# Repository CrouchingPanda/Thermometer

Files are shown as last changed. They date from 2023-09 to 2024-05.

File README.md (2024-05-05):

# Thermometer

Board for temperature measurement built around MLX90614 infrared surface temperature sensor.

## Platform

Arduino core used is Raspberry Pi Pico / RP2040 by Earle F. Philhower, III v3.7.0.

[InterboardSerial](https://github.com/CrouchingPanda/InterboardSerial) custom library is used 
for communicating with the calibration board.

## Libraries

| Title | Version |
|---|---|
| lvgl | 8.3.11  |
| TFT_eSPI | 2.5.34  |
| Smoothed | 1.2.0 |
| SerialTransfer | 3.1.3 |
| NeoPixelConnect | 1.2.0 |
| JLed | 4.13.1  |
| Adafruit MLX90614  | 2.1.5 |
| Adafruit LC709203F | 1.3.4 |
| Adafruit FT6206 | 1.1.0 |
| Adafruit BusIO | 1.15.0  |
| ArduinoJson | 7.0.3 |
| InterboardSerial | latest  |

## Theory Highlights

### For any object

```math
ε + R + 𝜏 = 1
```

$ε$ = Emissivity

$R$ = Reflectivity

$𝜏$ = Transmissivity

### For non-transparent object

```math
𝜏 = 0; ε + R = 1
```

### Stefan-Boltzmann Law

```math
M_e = P/A = εσ(T_o^4 - T_a^4)
```

$M_e$ = radiant exitance = defined as $P/A$

$P$ = energy per unit time = power = radiant flux

$A$ = area

$σ$ = Stefan's constant

$T_o$ = temperature of an object

$T_a$ = ambient temperature

### Sensor/object arrangement

```
 sensor (M_s)                                object
+-----------        emitted (M_o)           +------+
|            <==============================|      |
|            <-----------------------------_|      |
+-----------        reflected (M_r)        /|------+
                                          /
                                         /
                                        / ambient 
                                       / to be reflected									   
```

```math
M_s = M_o + M_r = εσ(T_o^4 - T_s^4) + Rσ(T_r^4 - T_s^4)
```

$M_s$ = total sensor exitance

$M_o$ = exitance coming from the object itself

$M_r$ = exitance coming from the surroundings = radiation reflected by the object

$T_o$ = object's temperature

$T_s$ = sensor's temperature (on its die)

$T_r$ = room (ambient, background) temperature

### Application

MLX90614 leverages the above to come up with its temperature readings. It has an element monitoring its own 
temperature, as well as another sensor registering incident energy flux. It uses an emissivity value of `1.00` 
by default. As a note, in the equation above the sensor's firmware assumes $T_s = T_r$.

A way to adjust the calculations for a different emissivity is to get the temperature reading from the device with
its default emissivity, thereby getting the incident flux value. Then use the above formula backward, using an arbitrary
emissivity of choice and now taking the temperature for the unknown variable.

Also, when doing calculations manually on MCU, the $T_s = T_r$ assumption can be tweaked, as it has been noted that 
in real-life scenarios the sensor can have higher temperature (perhaps due to self-heating) than the background.

### Calculations

First, we get both the object temperature $T_o$ as well as the sensor temperature $T_s$ with device's emissivity $ε$
set to `1.0`. For the sake of this example, we get $T_o = 73.0$ and $T_s = 69.0$. For the sake of simplicity the room 
temperature is assumed the same as the sensor temperature. Applying the equation above we get:

```math
M_s = 1 * σ * ((73.0)^4 - (69.0)^4) + (1 - 1) * σ * ((69.0)^4 - (69.0)^4)
```

```math
M_s / σ  = 5,731,120
```

Now we calculate the actual object temperature using what we believe is the real emissivity of whatever material 
we are measuring. Let's say the material is anodized aluminum with emissivity `0.77`. Applying the same formula
backward we get:

```math
M_s = 0.77 * σ * (T_o^4 - (69.0)^4) + 0.23 * σ * ((69.0)^4 - (69.0)^4)
```

```math
M_s / σ = 0.77 * T_o^4 - 17,453,683.17
```

```math
5,731,120 = 0.77 * T_o^4 - 17,453,683.17
```

```math
T_o^4 = 30,110,133.98
```

```math
T_o = 74.07
```

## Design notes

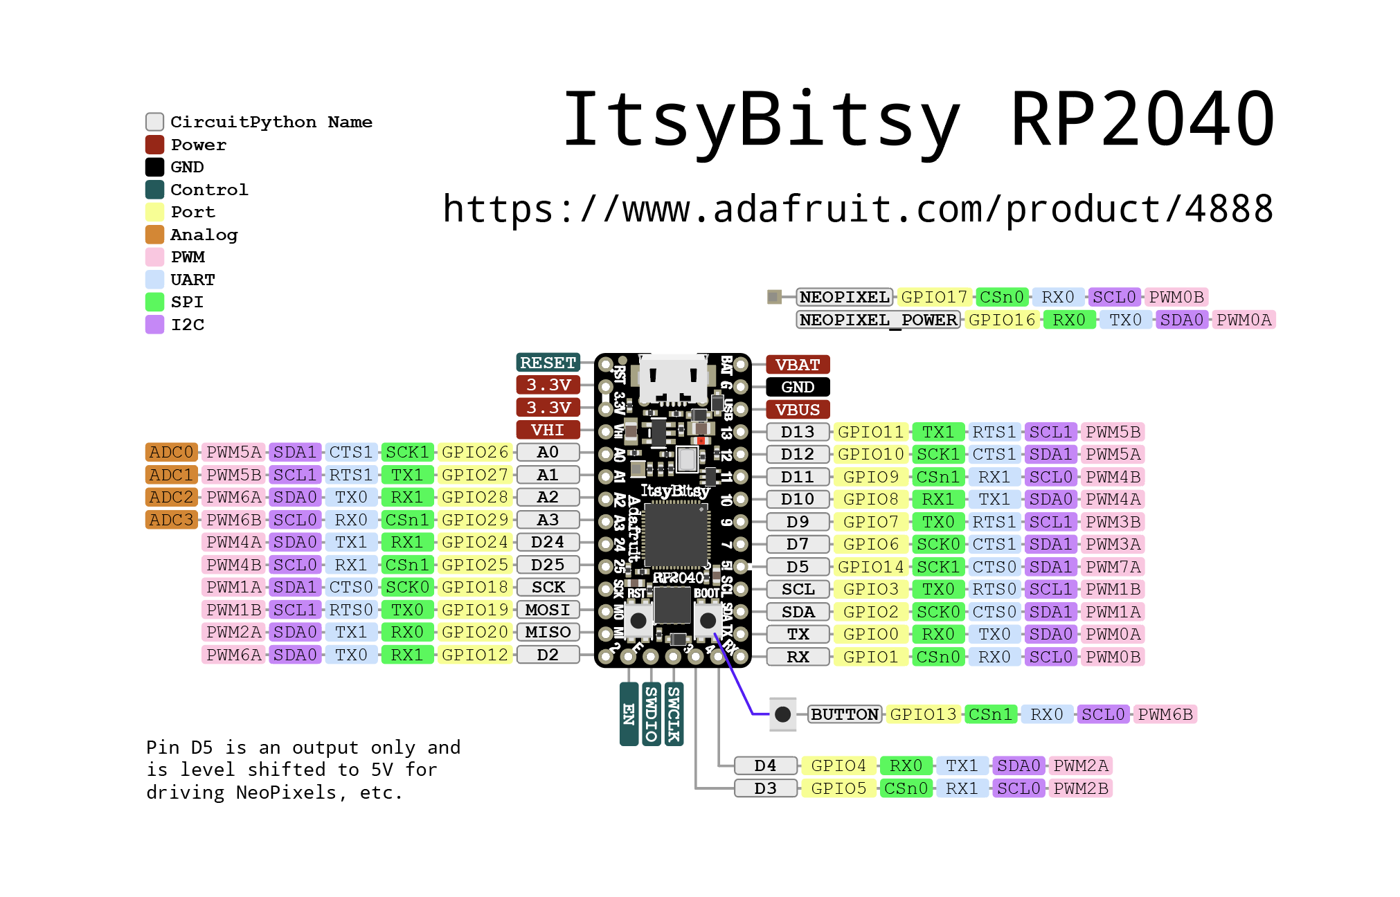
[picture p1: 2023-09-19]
resources/parts/ItsyBitsy RP2040 pinout.png

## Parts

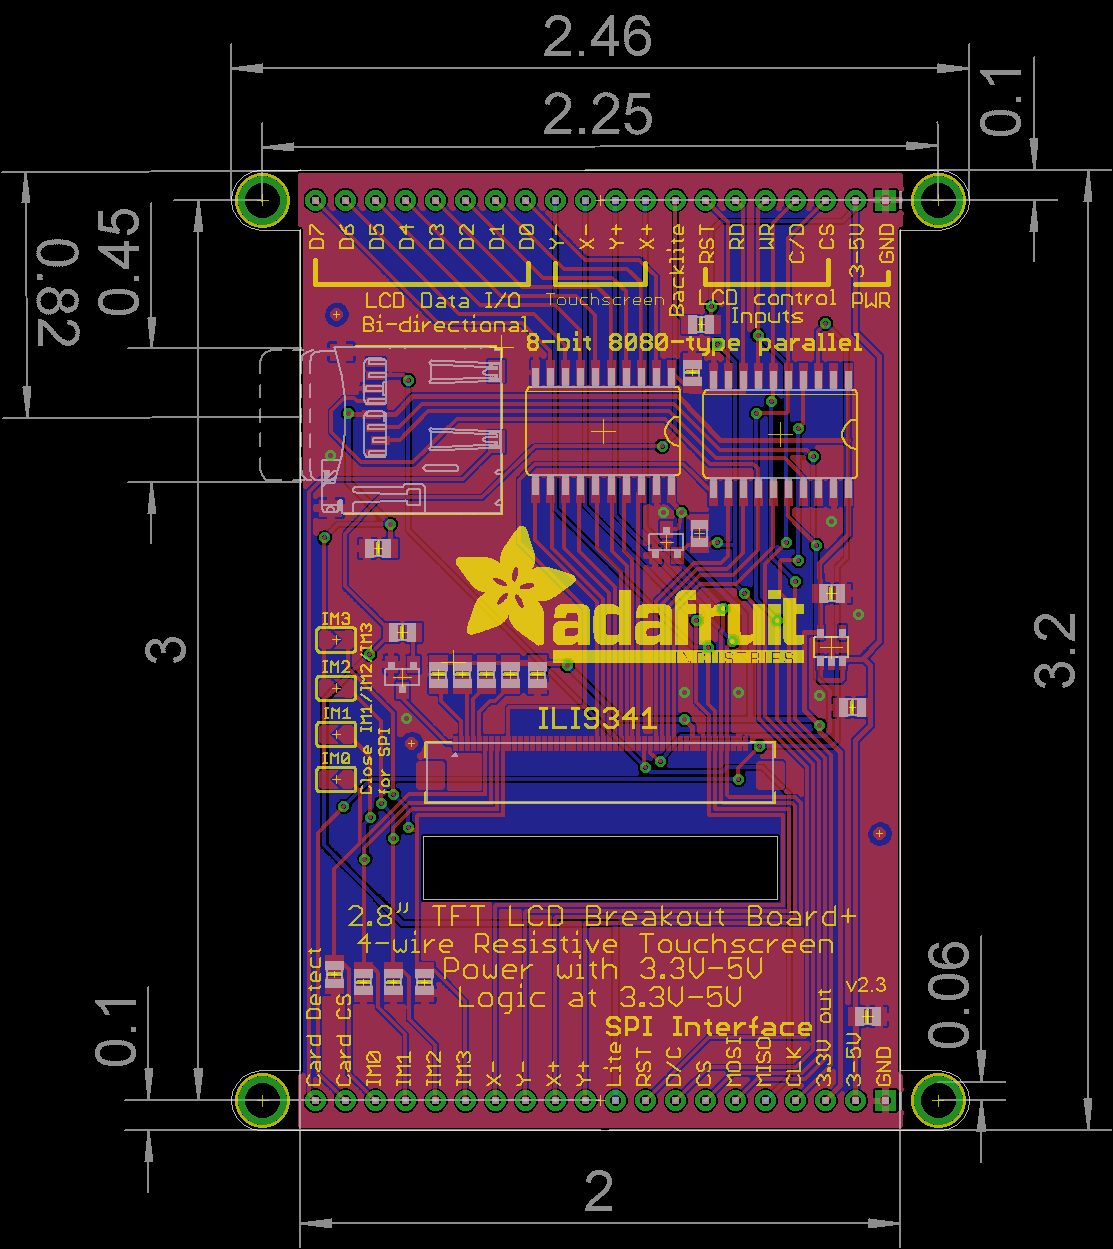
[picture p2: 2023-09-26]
resources/parts/adafruit_products_cap_touch.png

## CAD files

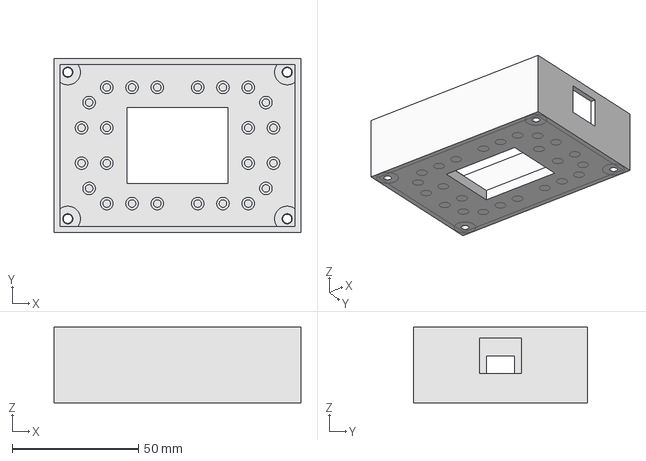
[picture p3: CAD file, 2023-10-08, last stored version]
resources/models/thermistor board case.FCStd
97.8 x 68.8 x 30.0 mm

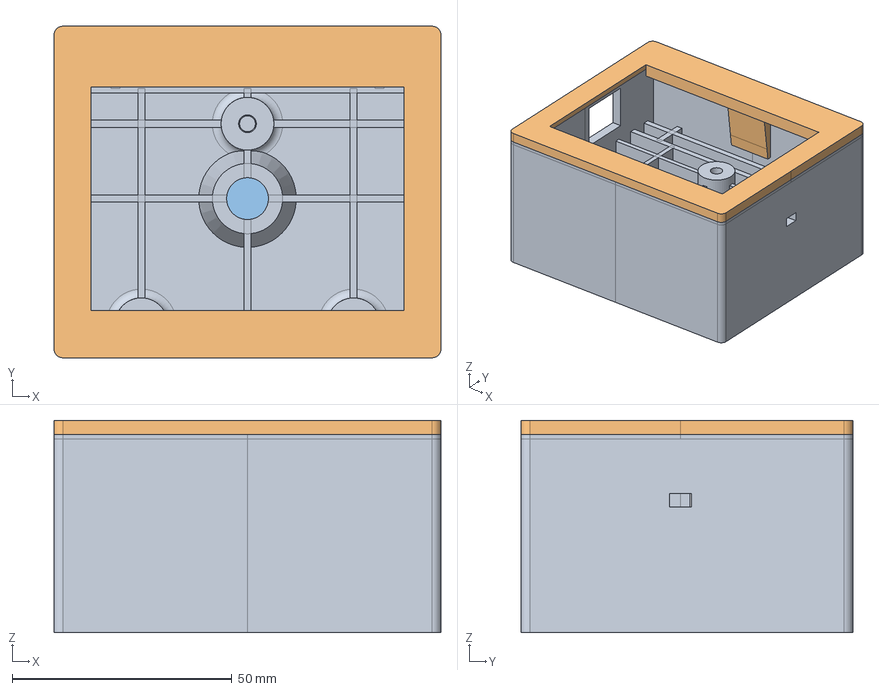
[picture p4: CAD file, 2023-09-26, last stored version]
resources/models/ir board case.FCStd
88.0 x 75.4 x 48.3 mm
Case
Lid
SensorPlug

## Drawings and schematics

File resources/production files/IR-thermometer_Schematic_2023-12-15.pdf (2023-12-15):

RX 20 TX 21 SDA 22 SCL 23 D5 24 D7 25 D9 26 D10 27 D11 28 D12 29 D13 30 VBUS 31 GND 32 VBAT 33

## ItsyBitsy

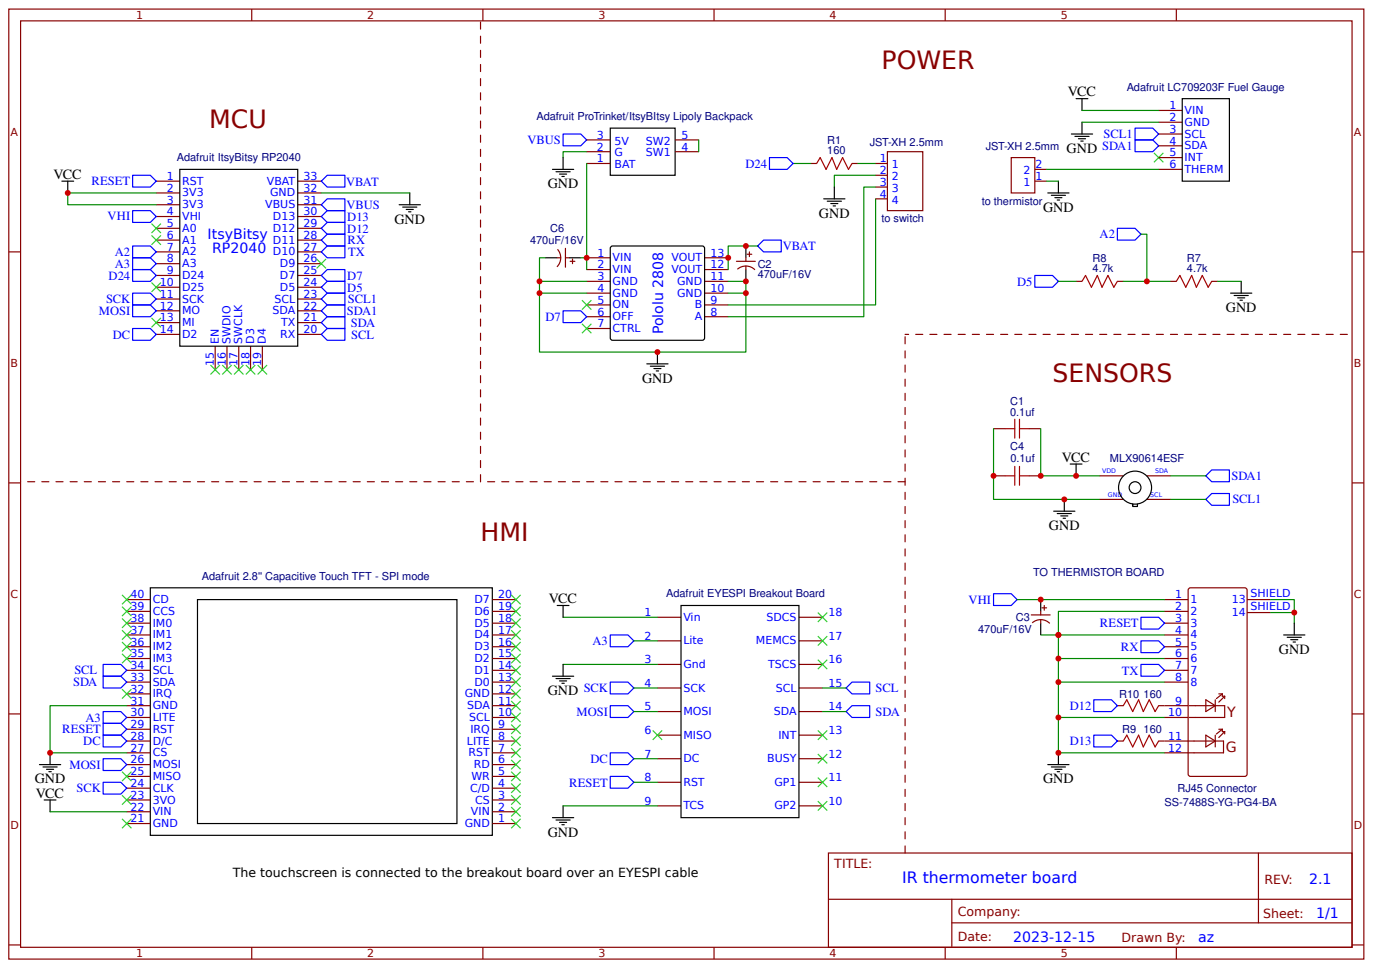
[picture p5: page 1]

Adafruit ProTrinket/ItsyBItsy Lipoly Backpack

Adafruit 2.8'' Capacitive Touch TFT - SPI mode

The touchscreen is connected to the breakout board over an EYESPI cable

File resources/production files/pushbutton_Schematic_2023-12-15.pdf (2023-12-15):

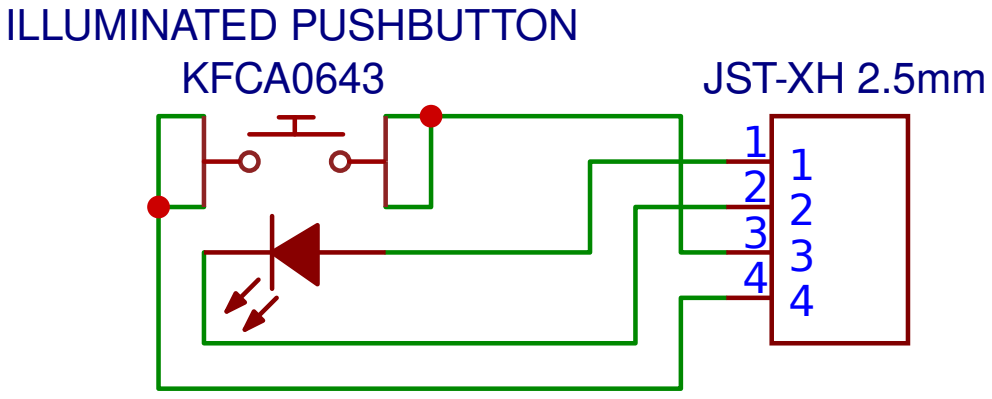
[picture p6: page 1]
JST-XH 2.5mm 1 1 2 2 3 3 4 4; ILLUMINATED PUSHBUTTON; TITLE:; Pushbutton breakout; REV: 1.0; Date:; Sheet: 1/1; Company:; KFCA0643

Drawn By: az

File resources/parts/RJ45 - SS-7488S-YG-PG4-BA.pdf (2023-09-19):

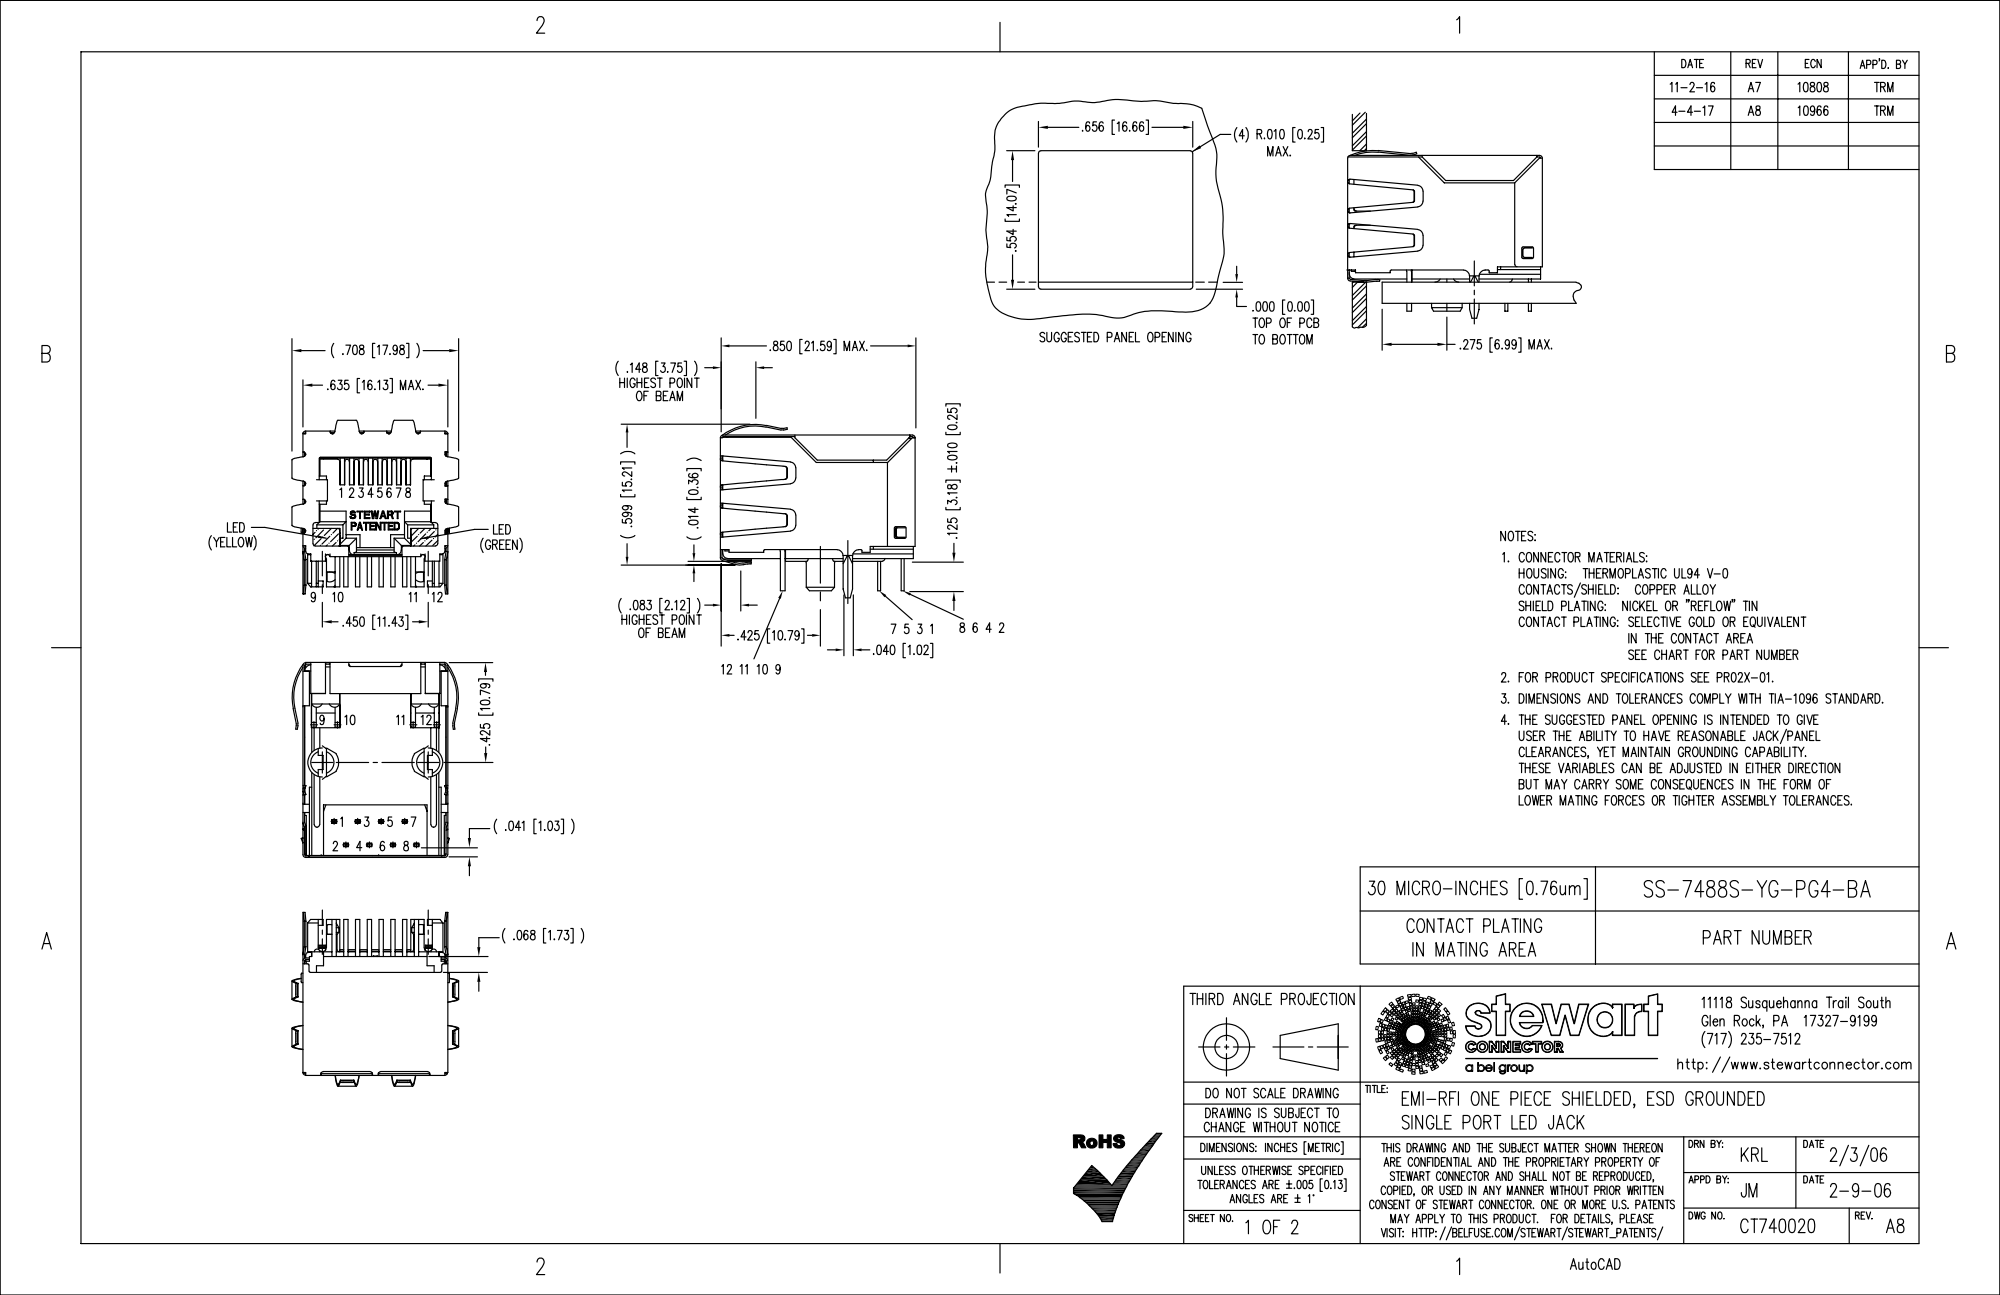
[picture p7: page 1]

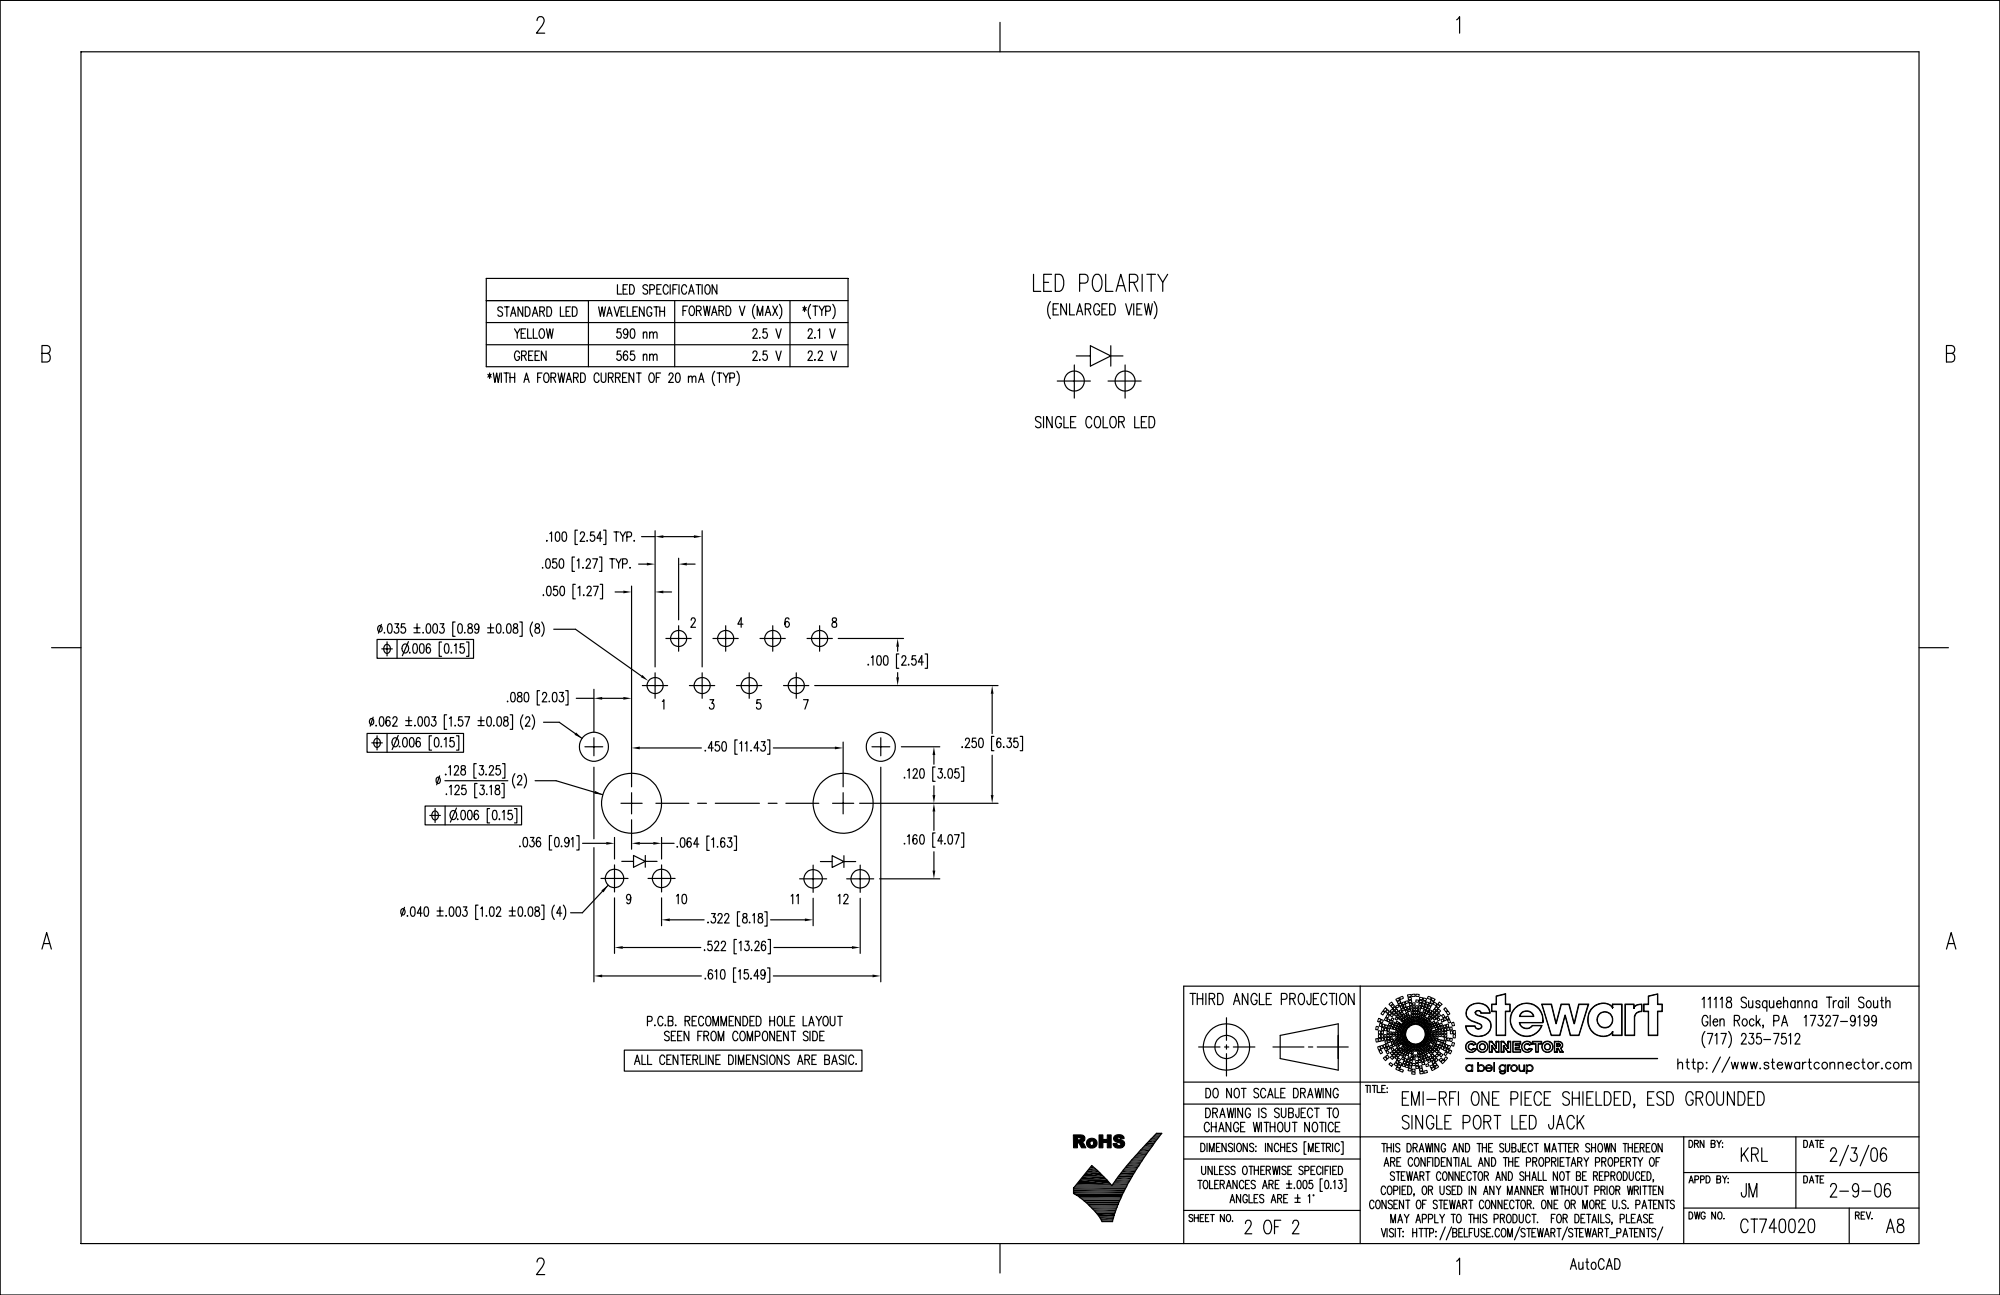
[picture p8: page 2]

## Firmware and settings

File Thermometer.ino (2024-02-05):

#include <Wire.h>

#include "src/hmi/HMI.h"
#include "src/calibration/CalibrationBoardReceiver.h"
#include "src/hardware/MelexisThermometer.h"
#include "src/hardware/Battery.h"
#include "src/hardware/PowerButtonLED.h"
#include "src/monitor/HealthMonitor.h"
#include "src/monitor/ActivityMonitor.h"

// faster doesn't work, not exactly sure why
constexpr uint32_t I2C_FREQUENCY = 70'000;

void setup() {
  HMI.begin();
  HMI.showLoadingScreen();
  HMI.setLoadingPercent(10);

  HealthMonitor.begin();
  HMI.setLoadingPercent(20);

  PowerLED.begin();
  HMI.setLoadingPercent(30);

  ActivityMonitor.begin();
  HMI.setLoadingPercent(40);

  Wire1.setClock(I2C_FREQUENCY);
  HMI.setLoadingPercent(50);

  Thermometer.begin();
  HMI.setLoadingPercent(60);

  LiPoBattery.begin();
  HMI.setLoadingPercent(70);

  CalibrationReceiver.begin();
  HMI.setLoadingPercent(80);

  HMI.startLvgl();
  HMI.setLoadingPercent(90);

  HMI.setObjectTemperatureWriter(
    [](){ return Thermometer.objectTemperatureFahrenheit(); }
  );

  HMI.setRoomTemperatureWriter(
    [](){ return Thermometer.roomTemperatureFahrenheit(); }
  );

  HMI.setOnDieTemperatureWriter(
    [](){ return Thermometer.onDieTemperatureFahrenheit(); }
  );

  HMI.setEmissivityWriter(
    [](){ return Thermometer.getEmissivity(); }
  );

  HMI.setEmissivityReader(
    [](float emissivity){ Thermometer.setEmissivity(emissivity); }
  );

  HMI.setBatteryPercentageWriter(
    [](){ return LiPoBattery.chargePercentage(); }
  );

  HMI.setBatteryChargingStatusWriter(
    [](){ return LiPoBattery.isCharging(); }
  );

  HMI.setBatteryTemperatureWriter(
    [](){ return LiPoBattery.temperatureFahrenheit(); }
  );

  HMI.setCalibrationBoardConnectionStatusWriter(
    [](){ return CalibrationReceiver.isConnected(); }
  );

  HMI.setPrimaryThermistorTemperatureWriter(
    [](){ return CalibrationReceiver.primaryThermistorTemperatureFahrenheit(); }
  );

  HMI.setSecondaryThermistorTemperatureWriter(
    [](){ return CalibrationReceiver.secondaryThermistorTemperatureFahrenheit(); }
  );

  HMI.onActivity(
    [](){ ActivityMonitor.registerActivity(); }
  );

  HMI.setLowPowerModeTimeoutWriter(
    [](){ return ActivityMonitor.getLowPowerTimeoutMins(); }
  );

  HMI.setPowerOffTimeoutWriter(
    [](){ return ActivityMonitor.getPowerOffTimeoutMins(); }
  );

  HMI.setLowPowerModeTimeoutReader(
    [](uint8_t minutes){ ActivityMonitor.setLowPowerTimeoutMins(minutes); }
  );

  HMI.setPowerOffTimeoutReader(
    [](uint8_t minutes){ ActivityMonitor.setPowerOffTimeoutMins(minutes); }
  );

  HMI.setPowerIndicatorOnBrightnessWriter(
    [](){ return PowerLED.getOnBrightness(); }
  );

  HMI.setPowerIndicatorMaxBreathBrightnessWriter(
    [](){ return PowerLED.getMaxBreathBrightness(); }
  );

  HMI.setPowerIndicatorOnBrightnessReader(
    [](uint8_t brightness){ PowerLED.setOnBrightness(brightness); }
  );

  HMI.setPowerIndicatorMaxBreathBrightnessReader(
    [](uint8_t brightness){ PowerLED.setMaxBreathBrightness(brightness); }
  );

  HMI.setObjectTemperatureSmoothingFactorWriter(
    []() { return Thermometer.getObjectTemperatureSmoothingFactor(); }
  );

  HMI.setObjectTemperatureSmoothingFactorReader(
    [](uint8_t factor) { Thermometer.setObjectTemperatureSmoothingFactor(factor); }
  );

  HMI.setRoomTemperatureOffsetWriter(
    []() { return Thermometer.getRoomTemperatureOffsetCelsius(); }
  );

  HMI.setRoomTemperatureOffsetReader(
    [](float offset) { Thermometer.setRoomTemperatureOffsetCelsius(offset); }
  );

  ActivityMonitor.onLowPowerMode(
    [](){ HMI.initLowPowerMode(); }
  );

  ActivityMonitor.onDefaultMode(
    [](){ HMI.initDefaultMode(); }
  );

  HMI.setLoadingPercent(100);
  HMI.switchFromLoadingScreen();
}

void loop() {
  LiPoBattery.isCharging() ? PowerLED.breathe() : PowerLED.on();
  HealthMonitor.run();
  CalibrationReceiver.run();
  ActivityMonitor.run();
  HMI.run();
}

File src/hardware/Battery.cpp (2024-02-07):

#include "Battery.h"

#include <stdint.h>

#include <Arduino.h>

#include <Wire.h>

#include <Adafruit_LC709203F.h>

constexpr uint16_t ADC_BITS = 12;

// we always read 1/2 of battery voltage because full (4.2V) is too much
// for the analog pin
constexpr float VOLTAGE_DIVIDER_RATIO = 2.0;
constexpr float MIN_CHARGING_VOLTAGE_MV = 4.5;
constexpr float REF_BOARD_VOLTAGE = 3.3;

constexpr uint8_t CHARGING_STATUS_CHECK_PIN = A2;
constexpr uint8_t VOLTAGE_PIN = 14;

// per LC709203F datasheet for 500mAh 3.7V battery
constexpr uint8_t BATTERY_APA = 0x10;
constexpr uint8_t BATTERY_PROFILE = 1;

// B25/B50 for thermistor P/N NXFT15XH103FEAB050
constexpr uint16_t BATTERY_THERMISTOR_B_VALUE = 3380;

void Battery::begin() {
  pinMode(VOLTAGE_PIN, OUTPUT);

  analogReadResolution(ADC_BITS);

  fuelGauge.begin(&Wire1);
  fuelGauge.setPowerMode(LC709203F_POWER_OPERATE);
  fuelGauge.setPackAPA(BATTERY_APA);
  fuelGauge.setBattProfile(BATTERY_PROFILE);
  fuelGauge.setTemperatureMode(LC709203F_TEMPERATURE_THERMISTOR);
  fuelGauge.setThermistorB(BATTERY_THERMISTOR_B_VALUE);
}

bool Battery::isCharging() {
  float vccPinVoltage = getVoltageReading(CHARGING_STATUS_CHECK_PIN);
  return vccPinVoltage >= MIN_CHARGING_VOLTAGE_MV;
}

float Battery::getVoltageReading(uint8_t pin) {
  digitalWrite(VOLTAGE_PIN, HIGH);

  uint16_t adcFraction = analogRead(CHARGING_STATUS_CHECK_PIN);
  float reading = adcFractionToVoltage(adcFraction) * VOLTAGE_DIVIDER_RATIO;
  
  digitalWrite(VOLTAGE_PIN, LOW);
  return reading;
}

float Battery::adcFractionToVoltage(uint16_t adc) {
  static float factor = REF_BOARD_VOLTAGE / (1u << ADC_BITS);
  return adc * factor;
}

uint8_t Battery::chargePercentage() {
  return fuelGauge.cellPercent();
}

float Battery::temperatureFahrenheit() {
  return fuelGauge.getCellTemperature() * 9.0 / 5.0 + 32.0;
}

Battery LiPoBattery = Battery();

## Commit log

2023-09-19 Add resources
    [USP10982 Thermistor RT Table.xlsx, ir board case.FCStd]
2023-09-26 Update IR thermometer model
    [ir board case.FCStd]
2023-09-29 Update thermistor board schematic
2023-10-08 Update schematics + pcb models
    [thermistor board case.FCStd]
2023-10-08 Fix I2C pins in IR schematic and pcb
2023-10-23 Update docs
    [USP10982 Thermistor RT Table.xlsx, ir board case.FCStd, thermistor board case.FCStd]
2023-10-23 Remove Thermistor code
2023-10-23 Make use of a custom ADC library in hardware code
2023-12-15 Update based on manufactured PCBs
2024-02-07 Fix thermistor specs in Battery.cpp
    [Battery.cpp]
2024-02-07 Set correct thermistor B value in Battery.cpp
    [Battery.cpp]
2024-02-08 Add battery thermistor datasheet
2024-03-09 Add 3d model of the PCB
